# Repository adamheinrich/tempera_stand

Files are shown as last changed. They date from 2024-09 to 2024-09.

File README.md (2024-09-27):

# Parametric 3D-printed stand for Tempera

This is a 3D-printable stand for the [Tempera synthesizer]. It consists of two
parts which attach to the VESA mounting holes on the bottom side and can be
customized in [OpenSCAD].

## BOM

Components used for one part (two needed in total):

- 2× Bottom rubber feet (diameter 12.7mm): 3M Bumpon series SJ5012 (7000001884)
- 2× M4 screws (depending on stand variant)

**Be careful when selecting screws. The maximum thread length inside Tempera is
5 mm. Longer screws may damage the inside.**

## Base stand

**Screws:** M4x8 (DIN 464)

The base stand in `tempera_stand.scad` has an angle of 28 degrees and attaches
using [DIN464 M4x8 screws].

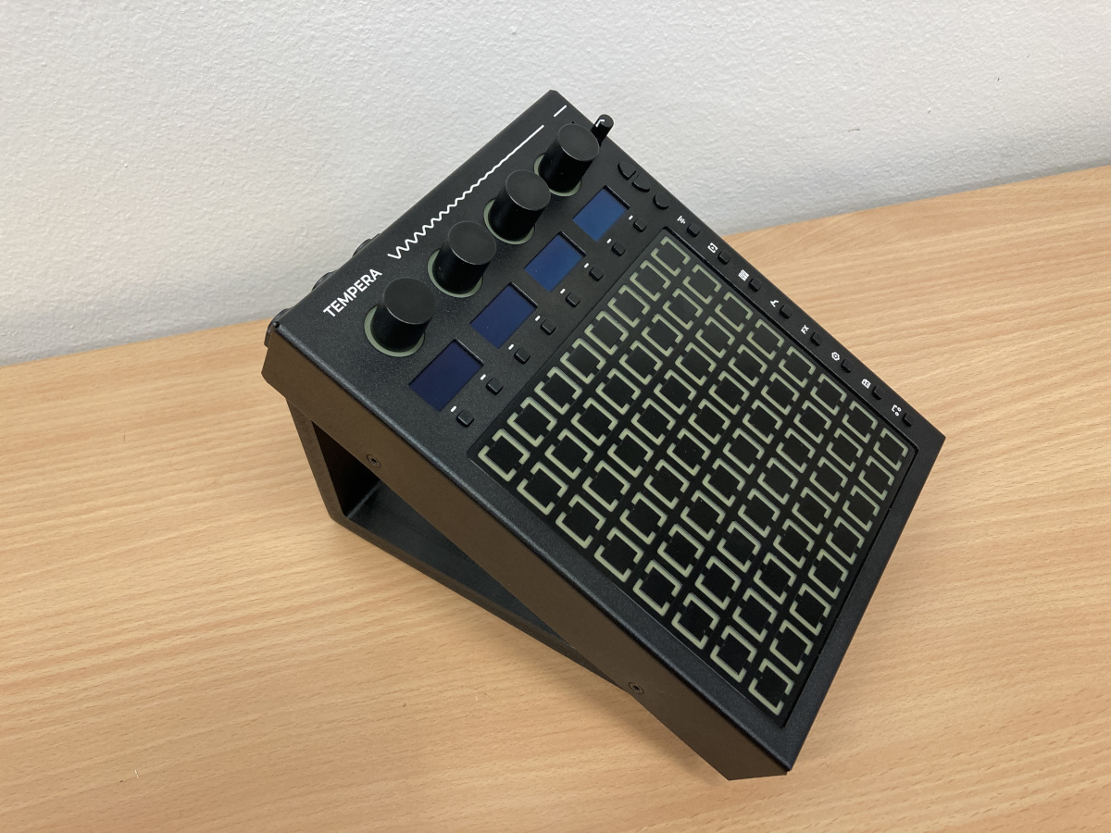
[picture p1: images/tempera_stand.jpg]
Base stand


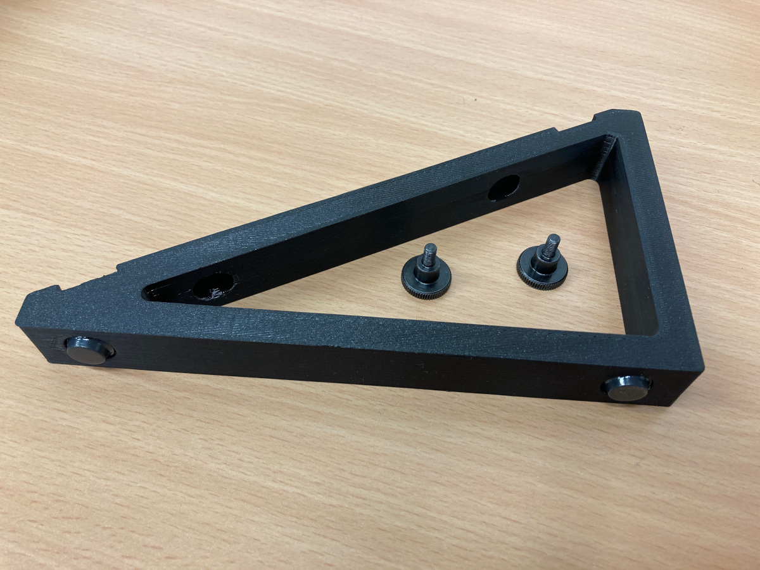
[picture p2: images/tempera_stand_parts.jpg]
Base stand (parts)


The stand can be also reversed for a steeper angle and an extra pair of rubber
feet can be mounted on the short side.

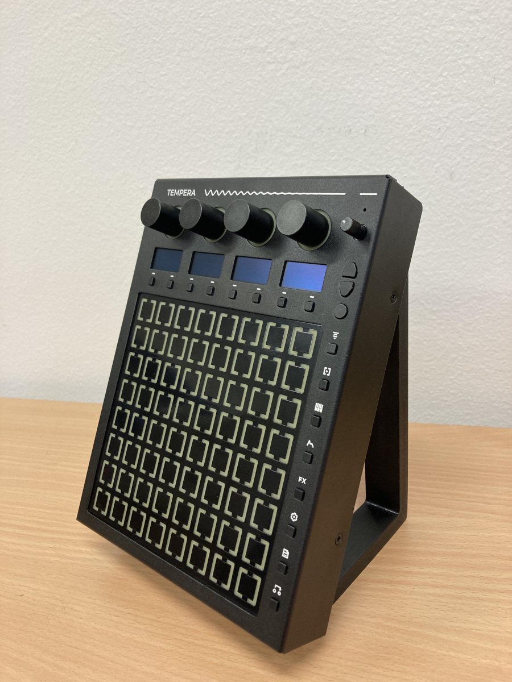
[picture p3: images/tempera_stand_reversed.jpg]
Base stand (reversed)


## Base stand without reversibility

**Screws:** M4x8 (DIN 464)

The base stand has a small step on the rear side which is required to be able to
reverse the stand and have Tempera mounted with an angle of 62° instead of 28°.
In case this is not required, the step can be removed as demonstrated in
file `tempera_stand_simplified.scad`.

## Low profile stand

**Screws**: M4x10 (inbus DIN 912)

The low profile stand in `tempera_stand_low.scad` has an angle of 15 degrees and
attaches using M4x10 inbus (hex) screws as there is not enough space for the
DIN464 screws. The screwdriver holes protrude through the whole body for easier
assembly.

Due to the small angle the stand is not reversible.

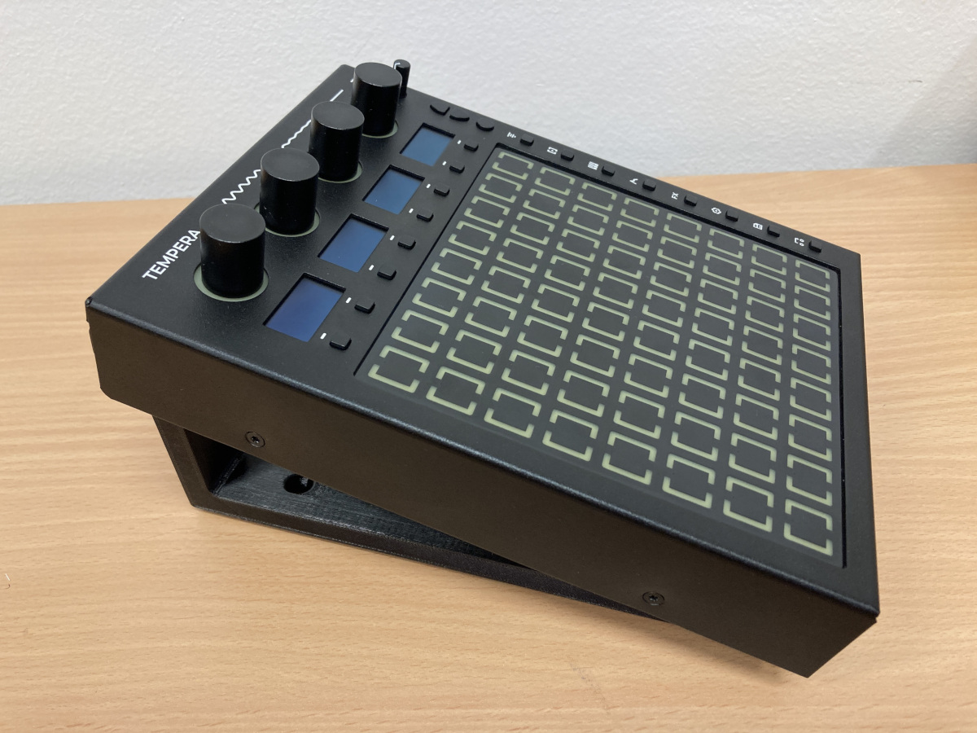
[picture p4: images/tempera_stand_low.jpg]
Low profile stand


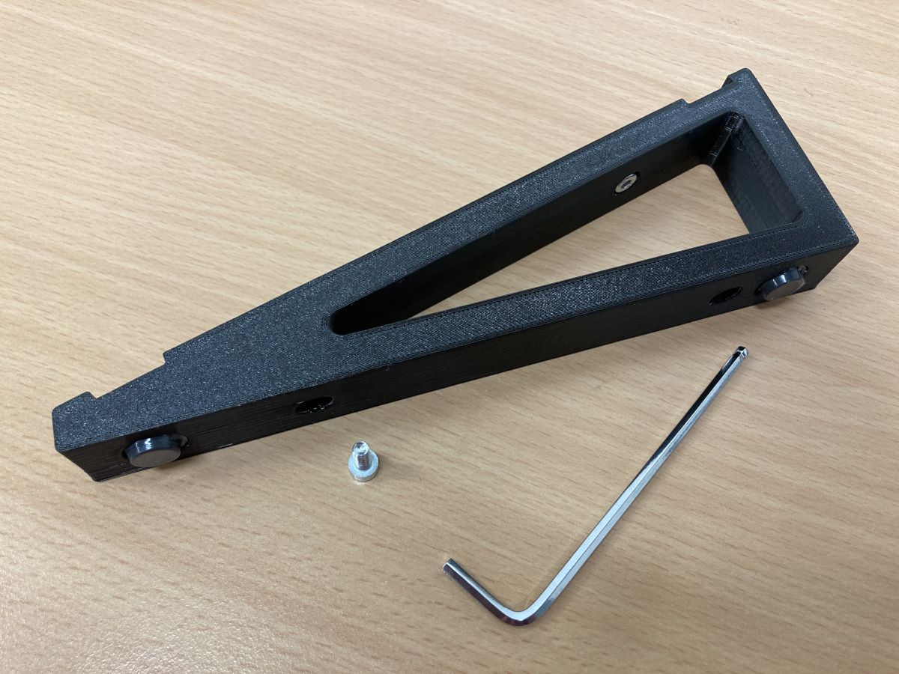
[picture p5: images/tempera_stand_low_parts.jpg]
Low profile stand (parts)


## Printing

The stand consists of two parts. Make sure to mirror the second part in the
slicer otherwise the cutouts for Tempera's rubber feet won't fit.

It's recommended to print with the rubber feet cutouts facing the heat bed --
this requires supports but has nicer finish on the surface facing outside.

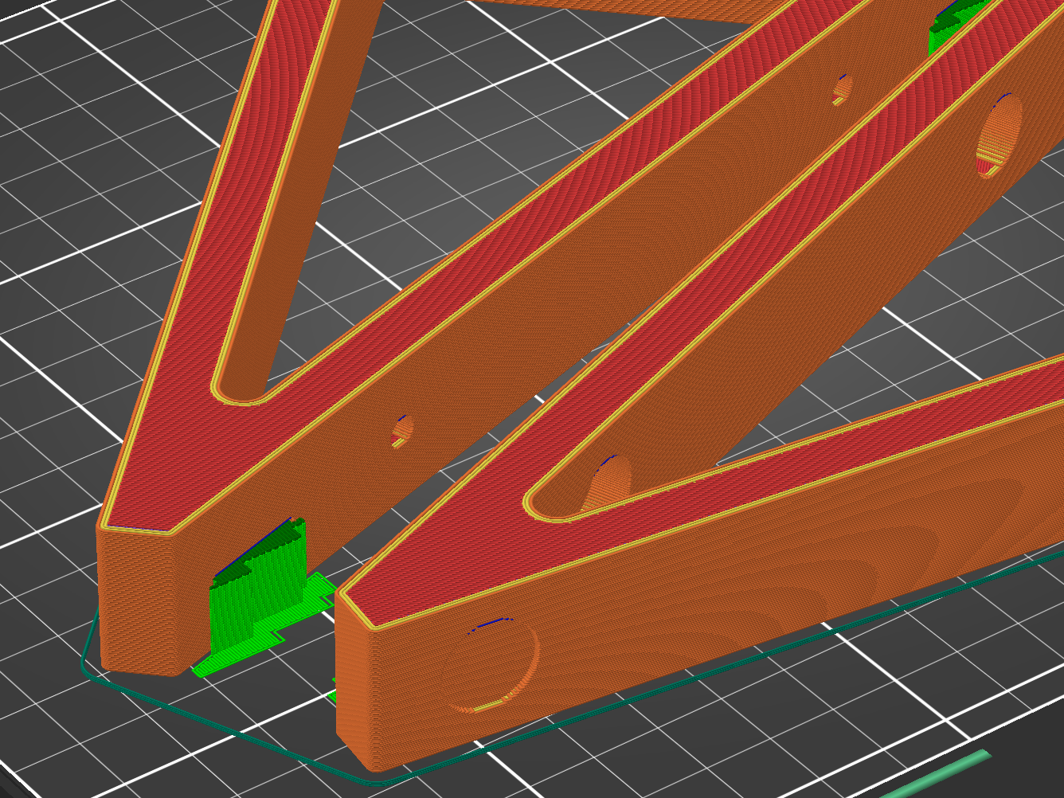
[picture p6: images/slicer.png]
Slicer configuration


## License

The Tempera stand is free software: you can redistribute it and/or modify it
under the terms of the GNU General Public License as published by the Free
Software Foundation, either version 3 of the License, or (at your option) any
later version.

See file `COPYING` for details.

[OpenSCAD]: https://www.openscad.org/
[Tempera synthesizer]: https://www.playtempera.com/
[DIN464 M4x8 screws]: https://www.tme.eu/en/details/din464-m4-8/knobs/elesa-ganter/din-464-m4-8/

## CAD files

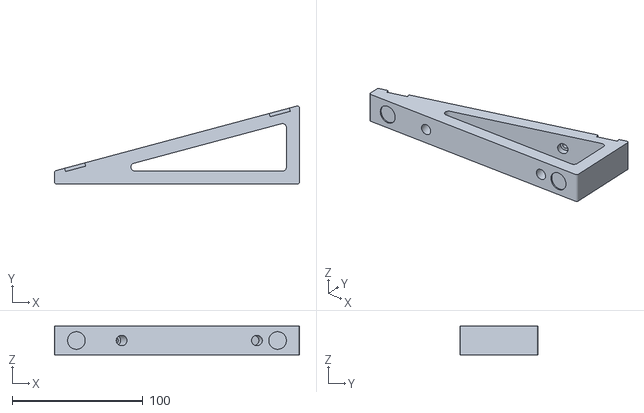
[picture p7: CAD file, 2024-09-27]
stl/tempera_stand_low.stl
187.4 x 59.8 x 22.0

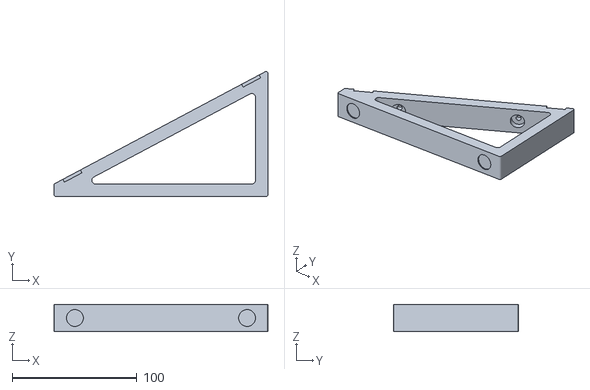
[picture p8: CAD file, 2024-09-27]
stl/tempera_stand_simplified.stl
171.3 x 100.1 x 22.0

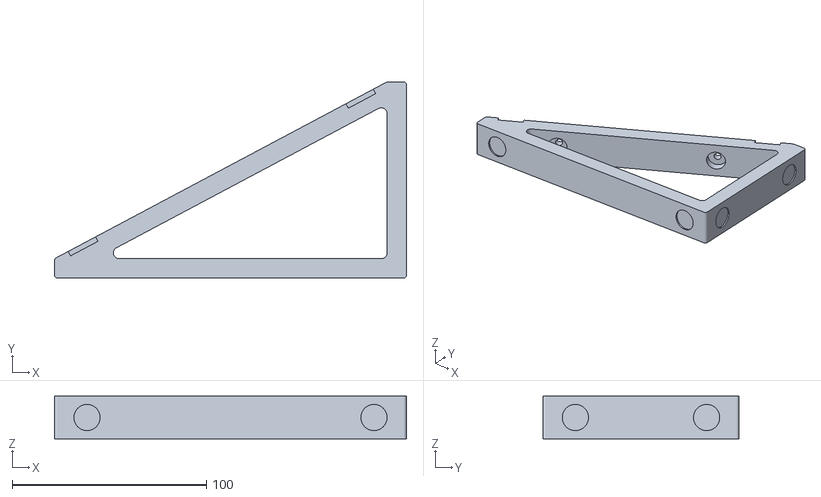
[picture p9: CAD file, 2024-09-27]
stl/tempera_stand.stl
181.3 x 101.1 x 22.0

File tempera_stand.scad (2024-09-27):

/*
 *  Parametric stand for the Tempera synthesizer
 *
 *  Copyright (C) 2024 Adam Heinrich <adam@beetlecrab.audio>
 *
 *  This program is free software: you can redistribute it and/or modify
 *  it under the terms of the GNU General Public License as published by
 *  the Free Software Foundation, either version 3 of the License, or
 *  (at your option) any later version.
 *
 *  This program is distributed in the hope that it will be useful,
 *  but WITHOUT ANY WARRANTY; without even the implied warranty of
 *  MERCHANTABILITY or FITNESS FOR A PARTICULAR PURPOSE.  See the
 *  GNU General Public License for more details.
 *
 *  You should have received a copy of the GNU General Public License
 *  along with this program.  If not, see <https://www.gnu.org/licenses/>.
 */

$fn = 100;

include <test_models.scad>;

/* Gear geometry: */
gear_size = 194;

gear_feet_size = 16;
gear_feet_to_hole = 31;
gear_feet_depth = 2.6;

mounting_hole_offset = 47;
mounting_hole_dist = 100; // VESA 100x100

/* Stand geometry: */
stand_thickness = 10;
stand_width = 22;

step_front = 10;
step_rear = step_front; // Useful for reversible stands (set step_rear = step_front)

shear = 0;
angle = 28;

r2 = 1.5;
r1 = r2 * 2;

/* Screw parameters
   MPN: DIN464-M4-8: */
screw_head_diameter = 12;
screw_thread_length = 8;

screw_depth = 5.5; // How much the screw is recessed inside the stand
screw_through = false;

/* Bottom rubber feet parameters
   MPN: 3M SJ5012 (7000001884): */
has_bottom_feet = true;
has_rear_feet = true;
foot_diameter = 12.7 + 0.8;
foot_depth = 1.0;
foot_edge_distance = 10;

/* Computed global variables: */
hyp = gear_size;
x = hyp * cos(angle);
y = hyp * sin(angle);

module stand_2d() {
    pts=[[0, step_front],
         [0, 0],
         [x + shear + step_rear, 0],
         [x + step_rear, y + step_front],
         [x, y + step_front]];

    difference() {
        offset(r=r2) offset(delta=-r2) {
            polygon(pts);
        }

        offset(r=r1) offset(delta = -(stand_thickness + r1)) {
            polygon(pts);
        }
    }
}

module stand_3d() {
    mirror([0, 0, 1])
    difference() {
        /* Main body: */
        linear_extrude(stand_width, center=true) {
            stand_2d();
        }

        /* Counterbore screw holes: */
        translate([0, step_front, 0]) {
            rotate([-90, 0, angle]) {
                for (p=[0, mounting_hole_dist]) {
                    dz = 0.05; // Why is this needed?
                    translate([mounting_hole_offset + p, 0, -stand_thickness - dz]) {
                        cylinder(d=4.4, h=1000);
                        cylinder(d=screw_head_diameter, h=screw_depth);

                        if (screw_through) {
                            rotate([0,180,0]) {
                                cylinder(d=screw_head_diameter, h=1000);
                            }
                        }
                    }
                }
            }
        }

        /* Gear feet cutouts (Tempera specific): */
        translate([0, step_front, 0]) {
            rotate([-90, 0, angle]) {
                for (p=[0, mounting_hole_dist] + [-1, 1] * gear_feet_to_hole) {
                    translate([mounting_hole_offset + p, stand_width/2, 0]) {
                        cube(
                            [gear_feet_size, stand_width, gear_feet_depth*2],
                            center=true
                        );
                    }
                }
            }
        }

        /* Bottom feet: */
        if (has_bottom_feet) {
            foot_pts = [
                foot_edge_distance + foot_diameter / 2,
                x + shear + step_rear - foot_edge_distance - foot_diameter / 2,
            ];
            rotate([90, 0, 0]) {
                for (dx=foot_pts) {
                translate([dx, 0, -foot_depth])
                    cylinder(d=foot_diameter, h=1000);
                }
            }
        }

        /* Rear feet: */
        if (has_rear_feet) {
            foot_pts = [
                foot_edge_distance + foot_diameter / 2,
                y + step_rear - foot_edge_distance - foot_diameter / 2,
            ];
            rotate([0, 90, 0]) {
                for (dy=foot_pts) {
                    translate([0, dy, x + shear + step_rear - foot_depth]) {
                        cylinder(d=foot_diameter, h=1000);
                    }
                }
            }
        }
    }
}


/* Output: */

thread_length_inside = screw_thread_length - (stand_thickness - screw_depth);
echo(str("Thread length inside Tempera: ", thread_length_inside, "mm"));

assert(
    thread_length_inside <= 5.0,
    "Thread length inside Tempera must be less than 5 mm, risk of damage!"
);

render_default = true; // Allows to override the rendering step
render_assembly = false; // Renders assembly for visual verification

if (render_default) {
    if (render_assembly) {
        stand_3d();
        tempera();
        screws_din464(0);
        //screws_inbus(0);
    } else {
        //mirror([0, 0, 1])
        stand_3d();
    }
}

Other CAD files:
tempera_stand_low.scad
tempera_stand_simplified.scad
test_models.scad
